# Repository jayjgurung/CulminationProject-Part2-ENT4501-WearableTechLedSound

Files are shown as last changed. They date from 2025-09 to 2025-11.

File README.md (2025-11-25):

# Audio-Visual Reactive System Tech

By Jay Jung Gurung — Emerging Media Technology | Culmination Project II (MTEC 4501)

## Overview

Audio-Visual Reactive System Tech is an interactive hardware–software system that transforms real-time audio input into dynamic LED visualizations. Built using an ESP32 microcontroller, an I2S MEMS microphone, WS2812B LEDs, and a custom PCB, this project explores embedded systems, acoustics, digital signal processing, and wearable audiovisual design.

The system analyzes incoming sound using an FFT (Fast Fourier Transform) and maps frequency energy to visual patterns, brightness, and color behavior. Additional control inputs (potentiometers, infrared remote, buttons, sensors) allow the user to modify the visual output and sensitivity on the fly.

This project aims to create an elegant, portable, and customizable audio-reactive LED module suitable for performance, stage design, wearables, and experimental media-technology applications.

---

## Features

- Real-time audio analysis via ESP32 I2S interface
- FFT-driven LED visualization (frequency bins → light patterns)
- Custom PCB designed in KiCad 8/9
- 3D-printed enclosure modeled in Autodesk Fusion 360
- WS2812B LED output with multiple animation modes
- Potentiometer-based sensitivity control
- Optional IR remote support for future expansion
- Modular design for wearable or tabletop use

---

## Hardware Components

- ESP32-WROVER-IE DevKit
- INMP441 (or similar) I2S MEMS microphone
- WS2812B LED strip or 5-LED chain
- Potentiometer for sensitivity
- IR receiver (optional)
- USB-C Li-ion charging board
- 21700 lithium battery
- Custom PCB (routed & manufactured)
- 3D-printed casing

---

## Software / Tools

- Arduino IDE (ESP32 Core v3.x)
- KiCad 8/9 (schematic & PCB design)
- Autodesk Fusion 360 (enclosure modeling)
- FastLED library
- arduinoFFT library
- ESP-IDF I2S driver (new API)

---

## Repository Structure

```text
CULMINATIONPROJECT-PART2-ENT4501-WEARABLETECHLEDSOUND/
│
├── Agile_Reports/
│   ├── 01_Agile_Sprint_Entry.md
│   ├── 02_Agile_Sprint_Entry.md
│   ├── 03_Agile_Sprint_Entry.md
│   ├── 04_Agile_Sprint_Entry.md
│   ├── 05.1_Agile_Sprint_Entry.md
│   └── 05.2_Agile_Sprint_Entry.md
│
├── Docs/
│   ├── Budget Report/
│   ├── KiCad/
│   ├── Panel Feedback/
│   ├── Reference/
│   └── Timeline/
│
├── Iteration_Plans/
│   └── IterationPlan-Roadmap.md
│
├── Presentations/
│   ├── Culmination-Part1-ProgressReport_Presentation_Fall2024.pdf
│   ├── Jury#1 Presentation links -JayGurung-fall2025.md
│   ├── Presentation_#2_JayGurung.pptx
│   └── Presentation-w-video-link.md
│
├── src/
│   ├── Arduino IDE/
│   └── KiCad/
│
├── .gitignore
└── README.md
```

---

## System Workflow

1. Microphone captures audio through I2S
2. ESP32 samples audio (e.g., 16 kHz)
3. FFT processes frames (e.g., 1024 samples)
4. Frequency bins are mapped to LED color, brightness, and animations
5. Potentiometer adjusts sensitivity threshold
6. LEDs render animations in real time

---

## Visual Modes (examples)

- Low-frequency pulsing
- Mid-range bar-graph effect
- High-frequency sparkle
- Full-spectrum rainbow reactive
- Silence → idle animation

---

## Current Status

- Hardware wiring and soldering complete
- PCB v1 assembled and tested
- Audio capture and FFT working
- LED visualization stable
- Pot control implemented
- 3D casing in prototype stage

---

## Acknowledgements

- Mentored by Professor Dr. David Smith
- Open-source libraries: FastLED, arduinoFFT
- Espressif documentation & community forums

---

## License

This project is for academic use under MTEC 4501 at City Tech. Feel free to reference or fork with credit.
Audio-Visual Reactive System Tech

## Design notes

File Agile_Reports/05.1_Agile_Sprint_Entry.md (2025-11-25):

Agile Sprint Log (Iteration Report)

Project Title: WearableTech-AV-JayG
Sprint #: 3
Date Range: Sept 18 – Sept 29 (Week 8 – 9 Development & Debugging Phase)
Prepared by: Jay J Gurung

⸻

1. Workflow Steps & Build Progress
	•	Power System
	•	Battery + USB-C charger integration continues to function as intended.
	•	Verified safe boot cycles under both USB and battery modes.
	•	Microcontroller & Processing
	•	ESP32-WROVER in use (selected for additional memory and I2S handling).
	•	FFT pipeline stable at 1024-point, 16 kHz sample rate.
	•	Implemented calibration via potentiometer input (GPIO34) to control sensitivity thresholds.
	•	LED Control
	•	WS2812B 5-LED chain mapped to FFT bands.
	•	Adjusted band thresholds to improve high-frequency LED triggering.
	•	Serial output added for monitoring per-band amplitude values.
	•	Microphone
	•	I2S MEMS microphone wiring complete (WS, SCK, SD pins verified).
	•	Confirmed digital input streaming with test code; calibration in progress.
	•	New Feature (IR Remote)
	•	Began integrating IR remote input for mode toggling (ambient vs. audio-reactive).

⸻

2. Component Upgrade Assessment
	•	Potentiometer
	•	Repurposed as a mic sensitivity dial.
	•	Verified analog input on GPIO34; prevents overdriving LED output.
	•	LEDs
	•	Improved mapping of treble band; now more responsive with realistic sound levels.
	•	IR Remote
	•	Testing basic IR decode library for ESP32.
	•	Initial command mapping planned (mode switching, brightness control).

⸻

3. Issues Encountered
	•	Permanent LED On
	•	Low-frequency LED occasionally stays lit due to baseline noise floor.
	•	Requires further threshold adjustment with pot + code calibration.
	•	Mic Sensitivity
	•	Potentiometer heating issue noted during testing; possible need for resistor or wiring adjustment.
	•	Code Stability
	•	Encountered I2S driver conflicts (resolved by switching to new API: i2s_std.h).
	•	Core dump errors observed when flashing larger builds; investigated memory allocation.

⸻

4. Updates to Code & Components
	•	Code
	•	Updated to new ESP32 I2S standard API (i2s_std.h).
	•	Added potentiometer input for live sensitivity scaling.
	•	Added serial debugging for band-by-band amplitude values.
	•	Started framework for IR remote handling.
	•	Components
	•	Installed and tested I2S MEMS microphone.
	•	Integrated potentiometer control into live loop.
	•	WS2812B LEDs tuned with adjusted thresholds.

⸻

5. Future Iterations
	•	Finalize IR remote integration (mode toggling, brightness presets).
	•	Smooth LED flicker using moving average or exponential filter.
	•	Optimize FFT bin grouping for better distribution across 5 LEDs.
	•	Document mic calibration process (pot vs. hard-coded thresholds).
	•	Begin preparing visuals/slides for Jury #1 presentation.

⸻

6. Research Findings
	•	ESP32-WROVER handles I2S mic + FFT without performance bottleneck.
	•	Potentiometer provides flexible live calibration but requires safe wiring to prevent overheating.
	•	High-frequency FFT bins naturally have lower amplitude; scaling adjustments improve LED balance.
	•	Switching from legacy i2s.h to i2s_std.h ensures compatibility with ESP32 core v3.x.

⸻

7. Next Steps
	•	Complete IR remote command mapping.
	•	Fine-tune mic baseline and LED band thresholds with real audio.
	•	Add smoothing algorithm to stabilize LED flicker.
	•	Update GitHub repo with new code + circuit diagrams.
	•	Prepare Jury #1 deck: slides covering overview, current build, timeline, and budget.

⸻

8. Summary

The project has progressed into an integrated wearable audio-reactive system. The ESP32-WROVER now runs FFT analysis with an I2S MEMS mic input, mapped to a 5-LED WS2812B chain. A potentiometer provides live sensitivity control, addressing threshold calibration challenges. IR remote functionality has been initiated for flexible mode switching. Remaining work focuses on fine-tuning mic sensitivity, smoothing LED response, and preparing for the Jury #1 presentation.

⸻

9. Disclosures
	•	Research and documentation assisted by ChatGPT-5.
	•	Report compiled in Agile format for Sprint #5.

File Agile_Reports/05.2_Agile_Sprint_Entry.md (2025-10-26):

Agile Report #5.2 — Culmination Project II
Student: Jay Jung Gurung
Date Range: October 12 – October 19, 2025

⸻

Reflection on Jury #1 Feedback

What did you decide to change, refine, or revise based on jury feedback?
I decided to create a body for the design to give it a tangible form and help the next jury better understand what my system can do visually and functionally. I also added more LEDs and a potentiometer for greater control and responsiveness.

What materials (presentation, written documentation, or prototype) need the most improvement?
I plan to extend the LED setup from 5 to 25 addressable LEDs, add three additional potentiometers for parameter control, and ideally 3D-print a custom housing to encase the system and enhance presentation quality.

⸻

Retrospective (After Jury #1)

What went well:
The presentation successfully demonstrated the system’s core features and concept.

What didn’t:
The lack of a defined body or enclosure made it harder for the jury to visualize the final product’s real-world application.

What I learned:
Form and presentation are equally important as function. Giving the prototype a physical identity helps communicate design intent and use case more effectively.

⸻

Current State

I currently have rough sketches, updated code, a working prototype, and supporting documentation. The foundation of the reactive LED system is stable and ready for integration into a physical form.

⸻

User Story (Next Sprint Focus)

As a tech student who is into music and videography, I want to give my system a form that can be mounted on top of a camera hot shoe, serving as a compact audio-reactive LED attachment.

⸻

Acceptance Criteria (Given–When–Then)

Given that the physical body is still under design,
When the structure is completed and assembled,
Then I will have a working prototype that can be demonstrated as a functional camera accessory.

⸻

Definition of Done (DoD)

When a physical body/enclosure is constructed for the system and integrated with the LED and control components, the prototype will be considered complete.

⸻

Goals (Steps Toward the DoD)
	1.	Design and model the 3D enclosure for the LED box or camera-mount version.
	2.	Expand the LED matrix from 5 to 25 addressable pixels.
	3.	Integrate additional potentiometers for multi-parameter control.

⸻

Blockers (as Help Requests)
	•	Access to a 3D printer or fabrication tools for creating the enclosure.
	•	Guidance on power management and circuit safety for the expanded LED setup.
	•	Support in testing multiple potentiometers with the current ESP32 configuration.

⸻

Next Steps
	•	Continue refining the code and hardware integration.
	•	Begin physical assembly and wiring of the 5×5 LED grid.
	•	Prepare visuals (sketches and short demo video) for Sprint 5.3 presentation.

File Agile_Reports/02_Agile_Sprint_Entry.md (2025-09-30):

Agile Sprint Log (Iteration Report)

Project Title: WearableTech-AV-JayG
Sprint #: 1.2
Date Range: Sept 2 – Sept 16 (Week 2 - 3 Research)
Prepared by: Jay J Gurung

⸻

Sprint Stage Checklist
	✓	Speculate / Plan 
	✓	Research
	•	Design
	•	Make / Produce
	•	Publish / Present
	•	Assess

⸻

0. Review of Previous Sprint (CORE)
	•	Previous Sprint Goal: Identify and evaluate microphone options beyond the unreliable electret module tested last semester.
	•	Achieved / Not Achieved: Achieved — researched multiple alternatives, clarified suitability.
	•	Problems or Bottlenecks Found: Confusion between analog MEMS (ICS-40730) and digital I²S options; difficulty ensuring compatibility with ESP32.
	•	Feedback Received (peer/faculty/AI): Encouraged to consider digital Electret microphones but research indicated INMP441 would be better alternative to avoid analog gain/noise issues.
	•	Carry-over Tasks: Select a specific mic breakout to purchase and integrate into ESP32 testing.

⸻

1. Speculate / Plan (CORE)
	•	Current Sprint Goal (based on last assessment): Decide on a microphone module and supporting components that meet project needs for amplitude + frequency analysis.
	•	Key Tasks (checklist):
	•	Research MEMS microphones (digital vs analog).
	•	Verify ESP32 compatibility with chosen mic.
	•	Assess battery and charger modules for powering ESP32 + LEDs.
	•   Planned Deliverables: Research summary; finalized microphone choice; BOM for power and protection parts.
	•	Research Needed: Amplitude vs frequency detection methods, FFT library needs, and wiring requirements for I²S.

⸻

2. Research (OPTIONAL)
    Questions Investigated:
        •   Which microphone can reliably provide both amplitude and frequency data?
        •   Is a digital I²S mic superior to analog electret/AGC modules for wearables?
        •   What supporting components are needed for ESP32 + LED jacket builds?
	Sources Consulted:
        •   INMP441 datasheets and Arduino/ESP32 I²S examples.
        •   DFRobot Fermion SEN0526 (ICS-43434 I²S MEMS mic) documentation.
        •   Comparison to analog electret modules (MAX9814, MAX4466).
        •   Battery datasheets (LI21700JSV-50) and charger module specs (DFR0668).
	Findings / Insights:
	    •   INMP441 / Fermion SEN0526 (ICS-43434) are digital I²S microphones, plug-and-play with ESP32, ideal for FFT analysis and amplitude detection.
	    •   Analog MEMS (ICS-40730, electret mics) require amplification/ADC and are less stable; not recommended for frequency analysis.
	    •   ESP32 DevKitC handles I²S data + FFT comfortably; S3 variant offers more I/O and DSP headroom.
	    •   Battery: Jauch 21700 (5000 mAh) with PCM + fuse provides adequate runtime (2+ hours with LEDs).
	    •   Charger: DFR0668 is compatible but limited to 500 mA; overnight charging acceptable for class project.

⸻

3. Assess (CORE)
	•	Successes This Sprint: Narrowed mic choice to Fermion SEN0526 (I²S MEMS digital), confirmed ESP32 compatibility, identified battery/charger solutions, and safety components (polyfuse, capacitor, data resistor).
	•	Current Bottlenecks: Charger speed (10–12 h full charge); may need higher-current charger in future iterations.
	•	Feedback Received (peer/faculty/AI): Confirmed viability of digital MEMS approach; recommended prebuilt charger modules instead of bare ICs.
	•	Adjustments for Next Sprint: Order microphone, ESP32, LED strips, and charger. Begin bench tests with I²S mic → FFT → LED mapping pipeline.

4. Shopping list:
    •  https://www.digikey.com/short/525hn9th

5. Disclosures:
    -   Reaserch Assisted by ChatGpt.
    -   Report Summary and Compilation Assisted by Chatgpt.
    -   Research Archive : https://chatgpt.com/share/68b726d3-7894-8006-bfcb-972431b2e975

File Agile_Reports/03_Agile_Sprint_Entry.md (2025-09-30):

Agile Sprint Log (Iteration Report)

Project Title: WearableTech-AV-JayG
Sprint #: 1.3
Date Range: Sept 2 – Sept 16 (Week 2 - 3 Research)
Prepared by: Jay J Gurung

⸻

1. Workflow Steps and Code Analysis
	•	Initialization
	•	Original sketch initializes pins for LED output.
	•	Sets up the microphone input (analog or I2S depending on component).
	•	Serial monitor used for debugging.
	•	Loop Execution
	•	Continuously reads microphone signal.
	•	Maps raw amplitude values into brightness values for LEDs.
	•	Updates LEDs based on the mapped amplitude.
	•	Functions
	•	setup(): Prepares the environment, serial communication, and I/O pins.
	•	loop(): Handles real-time microphone reading and LED updates.
	•	Issues: No modularization of frequency analysis, hard-coded thresholds, and inefficient LED update cycle.

⸻

2. Component Upgrade Assessment
	•	Microphone Upgrade
	•	Moving from simple analog microphones → I2S MEMS microphones (INMP441 or ICS-40730).
	•	Advantage: Digital signal, higher accuracy, lower noise, direct FFT compatibility.
	•	LEDs Upgrade
	•	Old: Basic LED strips or single RGB LEDs.
	•	New: Addressable LED strips (WS2812B or SK6812) → allows mapping frequencies to different LED zones.
	•	Processing Unit Upgrade
	•	ESP32 recommended over Arduino Uno for:
	•	Higher processing power.
	•	Native I2S support.
	•	Built-in WiFi for possible remote features.

⸻

3. Issues Identified in Previous Sketch
	•	Only amplitude detection (no frequency mapping).
	•	Raw analog input was noisy, causing inaccurate LED flicker.
	•	LED update loop was slow → visible lag.
	•	No support for scaling brightness or splitting audio into frequency bands.
	•	No modular functions (all logic was dumped inside loop() instead of being separated into smaller reusable blocks).

⸻

4. Updates to Code & Components
	•	Code Updates
	•	Integrate FFT (Fast Fourier Transform) to split audio into low, mid, high bands.
	•	Use smoothing algorithms (moving average) to reduce flicker.
	•	Optimize LED updates using libraries like FastLED or Adafruit NeoPixel.
	•	Create modular functions: readAudio(), analyzeFrequency(), updateLEDs().
	•	Component Updates
	•	Switch to I2S microphone module (INMP441).
	•	Use ESP32 DevKitC for higher processing and WiFi support.
	•	Add Li-ion battery + charger module (DFR0668, TP4056, etc.) for portability.
	•	Use 5V addressable LED strips with level shifter if needed.

⸻

5. Future Iterations
	•	Phase 1: Real-time audio amplitude → LED brightness.
	•	Phase 2: Frequency band analysis → map bass, mids, treble to different LED channels.
	•	Phase 3: Add WiFi control → remote app or OSC/MQTT protocol.
	•	Phase 4: Integrate with music apps (DJ software, Serato, Ableton) for synced visualizations.

⸻

6. Research Findings
	•	I2S MEMS microphones have better noise rejection and allow FFT processing directly.
	•	FFT libraries for ESP32 (ArduinoFFT, ESP-DSP) perform well in real-time for small sample sizes (e.g., 1024).
	•	Addressable LEDs (WS2812B) are industry standard for music-reactive installations.
	•	Power consumption: LED strips draw high current (up to 60mA per LED at full brightness white). A Li-ion + 5V boost converter is required.
	•	Remote options: ESP32 can publish FFT results over WiFi (MQTT/OSC) to external apps.

⸻

7. Next Steps
	•	Replace microphone with INMP441 and test I2S audio capture.
	•	Implement FFT analysis for 3 frequency bands.
	•	Map frequency bands to LED zones (bass = red, mids = green, highs = blue).
	•	Add smoothing to LED brightness changes.
	•	Power test with Li-ion + charger module.
	•	Begin planning WiFi integration for remote control.

8.  Summary

        The project is transitioning from a basic microphone-to-LED system into an advanced audio-reactive LED platform. The initial sketch was limited to amplitude detection and lacked modularity, frequency analysis, and efficient LED control. Planned upgrades include adopting an ESP32 for enhanced processing and WiFi capability, integrating I2S MEMS microphones for accurate audio input, and utilizing addressable LED strips for flexible visualization. Code improvements will focus on FFT-based frequency band analysis, smoothing algorithms, and optimized LED update routines. Future iterations are designed to map frequency ranges to LED zones, incorporate portable Li-ion power solutions, and enable WiFi-based remote control. The next steps involve testing the INMP441 microphone, implementing FFT, refining LED responsiveness, evaluating power consumption, and preparing for remote connectivity features.

9. Disclosures:
    -   Reaserch Assisted by ChatGpt 5: Agent Mode
    -   Report Summary and Compilation Assisted by Chatgpt.

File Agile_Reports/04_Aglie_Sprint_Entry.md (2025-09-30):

Agile Sprint Log (Iteration Report)

Project Title: WearableTech-AV-JayG
Sprint #: 2
Date Range: Sept 13 – Sept 17 (Week 4 – 7 Research & Build Progress)
Prepared by: Jay J Gurung

⸻

1. Workflow Steps & Build Progress
	•	Power System
	•	Integrated rechargeable lithium-ion battery module with USB-C charger board.
	•	Added physical power switch to control current flow between the battery and ESP32.
	•	System successfully runs untethered from USB power.
	•	Microcontroller & Processing
	•	ESP32 DevKitC in use (chosen for I2S mic support and FFT capability).
	•	Current code implements FFT with 5 frequency bands (bass → treble).
	•	LED Control
	•	WS2812B addressable LED chain installed with 5 LEDs.
	•	Each LED mapped to one frequency band.
	•	LEDs respond to FFT magnitudes with brightness scaling.
	•	Microphone
	•	Microphone hardware selection done (I2S MEMS mic planned).
	•	Physical installation step remains pending.

⸻

2. Component Upgrade Assessment
	•	Battery & Power
	•	Added lithium-ion battery with charger board (USB-C).
	•	Power switch for safe on/off control during battery mode.
	•	LEDs
	•	Transitioned from earlier 3-band mapping to 5-band LED chain.
	•	Microphone
	•	I2S microphone module is the next hardware addition for clean signal capture.

⸻

3. Issues Encountered
	•	One LED in chain remained permanently on until sensitivity values are tuned.
	•	Mic not yet installed, preventing real-world FFT validation.
	•	Sensitivity thresholds for each band need calibration.

⸻

4. Updates to Code & Components
	•	Code
	•	Expanded FFT from 3 to 5 bands.
	•	LED mapping scaled to 5 LEDs, one per band.
	•	Serial monitor support being prepared for debugging loudness per band.
	•	Components
	•	Added rechargeable battery + USB-C charger board.
	•	Integrated hardware power switch.
	•	WS2812B LED chain mounted and responsive.

⸻

5. Future Iterations
	•	Install I2S MEMS microphone (INMP441 or equivalent).
	•	Fine-tune sensitivity thresholds for LED response.
	•	Add smoothing filters to reduce flicker.
	•	Test full portable operation (battery run-time).
	•	Begin exploring optional WiFi/OSC expansion for remote monitoring.

⸻

6. Research Findings
	•	5-band frequency mapping provides more dynamic visualization than 3-band setup.
	•	ESP32 performance remains stable with 1024-point FFT at 16 kHz sample rate.
	•	Battery operation with switch provides safe, portable use case.
	•	Addressable LEDs (WS2812B) continue to be efficient for small band-to-LED mapping.

⸻

7. Next Steps
	•	Complete installation of microphone.
	•	Validate FFT input against real sound sources.
	•	Calibrate LED sensitivity values via Serial monitor testing.
	•	Document portable power consumption with multimeter readings.

⸻

8. Summary

The project has advanced from planning into a functional 5-band audio-reactive LED system powered by a rechargeable lithium-ion battery. A USB-C charger module and physical switch ensure safe, portable operation. The ESP32 executes FFT processing and drives 5 WS2812B LEDs mapped to 5 frequency bands. The next major milestone is the installation and calibration of the I2S microphone, which will enable true real-time audio reactivity. Once the mic is integrated, the focus will shift to tuning LED sensitivity, smoothing, and preparing for possible WiFi expansion.

⸻

9. Disclosures
	•	Research and documentation assisted by ChatGPT-5.
	•	Report compiled in Agile format for Sprint #4.

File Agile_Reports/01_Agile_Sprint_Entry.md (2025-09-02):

Project Title: WearableTech-AV-JayG
Sprint #: 1
Date Range: Sept 2 - Sept 16 (Week 2 & Week 3)
Prepared by: Jay J Gurung

Purpose: 
The purpose of this sprint is to asses and identify, plan refine my project ideas at where it stands and overcome some challenges facing the projects in small steps.

The goal of the first half of my Culmination Project was to assemble a rough prototype that could manage to do some basic physical computing processes like reading and reacting to the input it is given. Although it did do some basic things I ran into some issues with the type of microphone sensor i had, which did not behave as planned.
    Although I am happy with what I got done so far, I would need to do some extensive research so I can find the right microphone that can read and react to it as it should.
THe Microphone I aquired had sensitive potentiometer that was not consistant with the reading, on top of that it could only read the amplitude. While my project required a mic that could read amplitude and frequency of the live audio, my attempt to get just use the amplitude reading did not fully work as planned because of unreliable hardware component in the mic unit.
    The feedback i received can be found in documents posted in the following  directory: "Docs/PanelFeedback-Fall2024" 
Images, documentation and video demo of my project's latest progress can be found in "Assets" folder.

My plan for the next 2 weeks is to Research on microphone sensors, and aquire the right components and test it in the Arduion IDE. In addition, I will be modifying the code in "/Prototype_Code" folder to cater to the needs of the new mic component.
    My target before Week4 is to be able to communicate LED lights with with the mic using IDE.

Checklist:
    1. Research microphone for Arduino 
    2. Order parts
    3. Communicate and program the sensor and output.
    4. Refine

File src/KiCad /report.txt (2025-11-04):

Warning: Width correction constrained.  The width correction value must be in the range of [0.000001 mm; 0.199999 mm] for the current design rules.
Plotted to '/Users/jayjgurung/Library/CloudStorage/GoogleDrive-jay.gurung@mail.citytech.cuny.edu/My Drive/FALL 2025/CulminationProject-Part2-ENT4501-WearableTechLedSound/KiCad /GERBER/ReactiveLED-PCB-F_Cu.gtl'.
Plotted to '/Users/jayjgurung/Library/CloudStorage/GoogleDrive-jay.gurung@mail.citytech.cuny.edu/My Drive/FALL 2025/CulminationProject-Part2-ENT4501-WearableTechLedSound/KiCad /GERBER/ReactiveLED-PCB-B_Cu.gbl'.
Plotted to '/Users/jayjgurung/Library/CloudStorage/GoogleDrive-jay.gurung@mail.citytech.cuny.edu/My Drive/FALL 2025/CulminationProject-Part2-ENT4501-WearableTechLedSound/KiCad /GERBER/ReactiveLED-PCB-F_Paste.gtp'.
Plotted to '/Users/jayjgurung/Library/CloudStorage/GoogleDrive-jay.gurung@mail.citytech.cuny.edu/My Drive/FALL 2025/CulminationProject-Part2-ENT4501-WearableTechLedSound/KiCad /GERBER/ReactiveLED-PCB-B_Paste.gbp'.
Plotted to '/Users/jayjgurung/Library/CloudStorage/GoogleDrive-jay.gurung@mail.citytech.cuny.edu/My Drive/FALL 2025/CulminationProject-Part2-ENT4501-WearableTechLedSound/KiCad /GERBER/ReactiveLED-PCB-F_Silkscreen.gto'.
Plotted to '/Users/jayjgurung/Library/CloudStorage/GoogleDrive-jay.gurung@mail.citytech.cuny.edu/My Drive/FALL 2025/CulminationProject-Part2-ENT4501-WearableTechLedSound/KiCad /GERBER/ReactiveLED-PCB-B_Silkscreen.gbo'.
Plotted to '/Users/jayjgurung/Library/CloudStorage/GoogleDrive-jay.gurung@mail.citytech.cuny.edu/My Drive/FALL 2025/CulminationProject-Part2-ENT4501-WearableTechLedSound/KiCad /GERBER/ReactiveLED-PCB-F_Mask.gts'.
Plotted to '/Users/jayjgurung/Library/CloudStorage/GoogleDrive-jay.gurung@mail.citytech.cuny.edu/My Drive/FALL 2025/CulminationProject-Part2-ENT4501-WearableTechLedSound/KiCad /GERBER/ReactiveLED-PCB-B_Mask.gbs'.
Plotted to '/Users/jayjgurung/Library/CloudStorage/GoogleDrive-jay.gurung@mail.citytech.cuny.edu/My Drive/FALL 2025/CulminationProject-Part2-ENT4501-WearableTechLedSound/KiCad /GERBER/ReactiveLED-PCB-User_Drawings.gbr'.
Plotted to '/Users/jayjgurung/Library/CloudStorage/GoogleDrive-jay.gurung@mail.citytech.cuny.edu/My Drive/FALL 2025/CulminationProject-Part2-ENT4501-WearableTechLedSound/KiCad /GERBER/ReactiveLED-PCB-Edge_Cuts.gm1'.
Created Gerber job file '/Users/jayjgurung/Library/CloudStorage/GoogleDrive-jay.gurung@mail.citytech.cuny.edu/My Drive/FALL 2025/CulminationProject-Part2-ENT4501-WearableTechLedSound/KiCad /GERBER/ReactiveLED-PCB-job.gbrjob'.
Info: Done.
Info: Done.

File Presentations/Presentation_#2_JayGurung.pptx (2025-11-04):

## REACTIVE LED SYSTEM

CULMINATION PROJECT
CITY TECH
2025 / FALL / NOVEMBER 4

Jay J Gurung

## Contents Jay J Gurung REACTIVE LED SYSTEM

1.

2.

PRODUCT DESIGN INSPO & SKETCH

SYSTEM UPGRADE & EXPANSION

PCB DESIGN - KiCad

ENCLOSURE DESIGN - Autodesk Fusion

NEXT STEPS

3.

4.

5.

## Jay J Gurung REACTIVE LED SYSTEM CAMVATE 96led Camera Video Fill Light SmallRig RM 25C Mini LED Video Light RGB PANEL PRO 2.0 1. PRODUCT DESIGN INSPIRATIONS

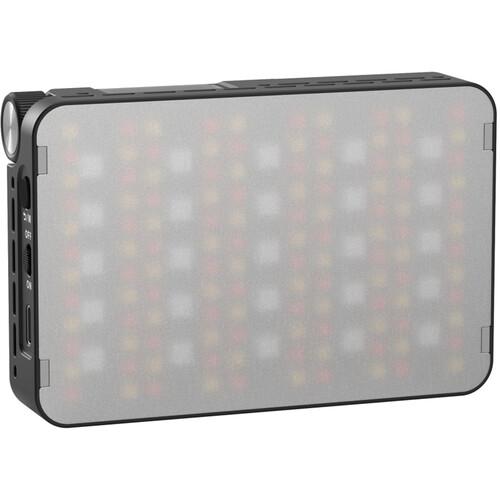
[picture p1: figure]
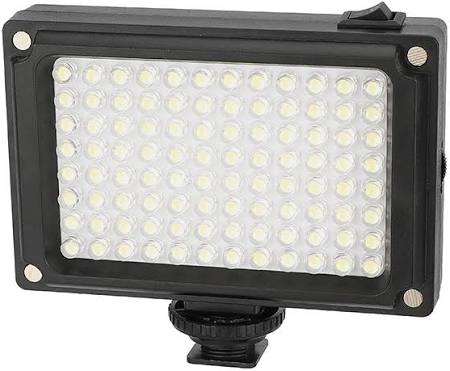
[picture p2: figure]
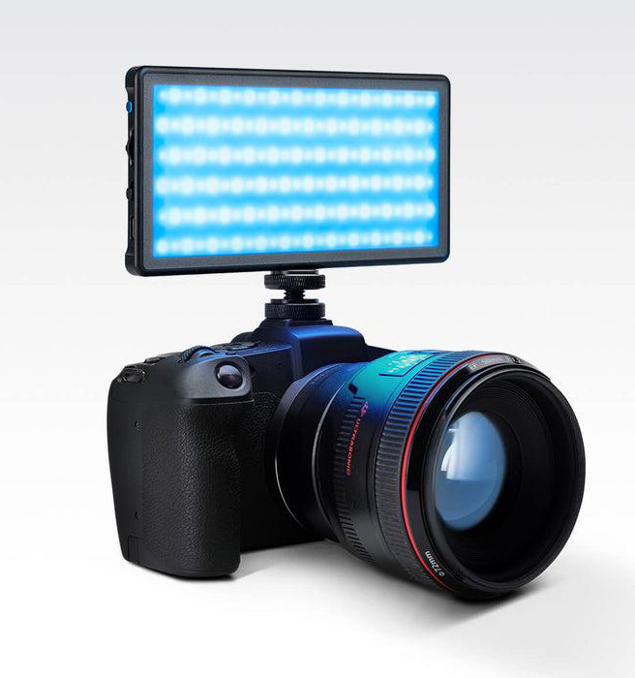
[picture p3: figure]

Controllable via App
RGB Colors
Rechargeable
Price $149
link (https://lumecube.com/products/panel-pro?nbt=nb%3Aadwords%3Ax%3A21932544690%3A%3A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)

SIMPLE LED with magnetic filter attachment, white or yellow temperature.
Runs on 2 AA batteries
Price $20
Link (https://www.camvate.com/products/camvate-96led-camera-video-fill-light-for-vlogging-studio-photography-3452)

Rechargable.
Adjustable Color Temp knob
Price $60
Link (https://www.bhphotovideo.com/c/product/1903738-REG/smallrig_5357_rm_25c_mini_led.html/?ap=y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)

## REACTIVE LED SYSTEM 1. PRODUCT DESIGN SKETCH Jay J Gurung

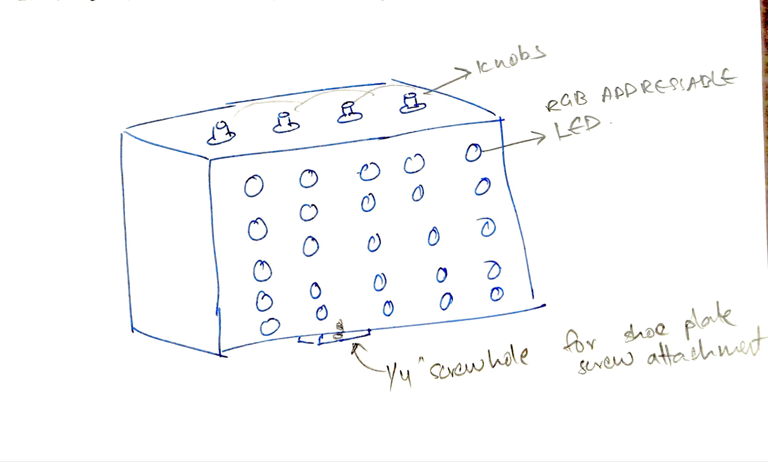
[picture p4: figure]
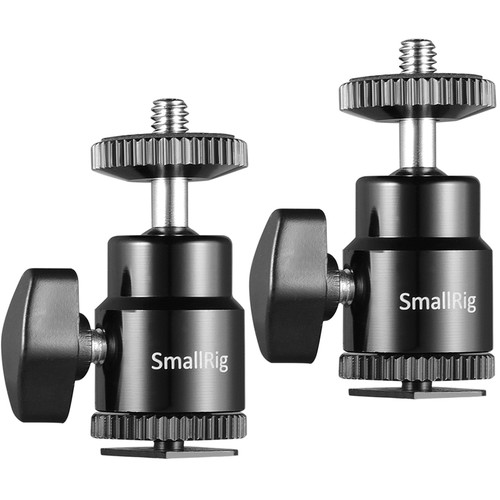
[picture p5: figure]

Expanded from 5 LED to 25 5 LEDs are mapped to each bandwidth instead of 1 LED for each bandwidth. Adds more brightness. System scalability. Will be adding more features. Updated the sketch to account for addressable LED to work with 25 LEDS.
Updated the sketch to account for 3 new pots. Functions not assigned yet. Changes Made What It Does Expanded from 1 control knob to 4 pots. Arduino IDE Sketch 3.0 Jay J Gurung Company Name 2. SYSTEM EXPANSION 1 2 3

## REACTIVE LED SYSTEM 3. PCB DESIGN - SCHEMATICS Jay J Gurung

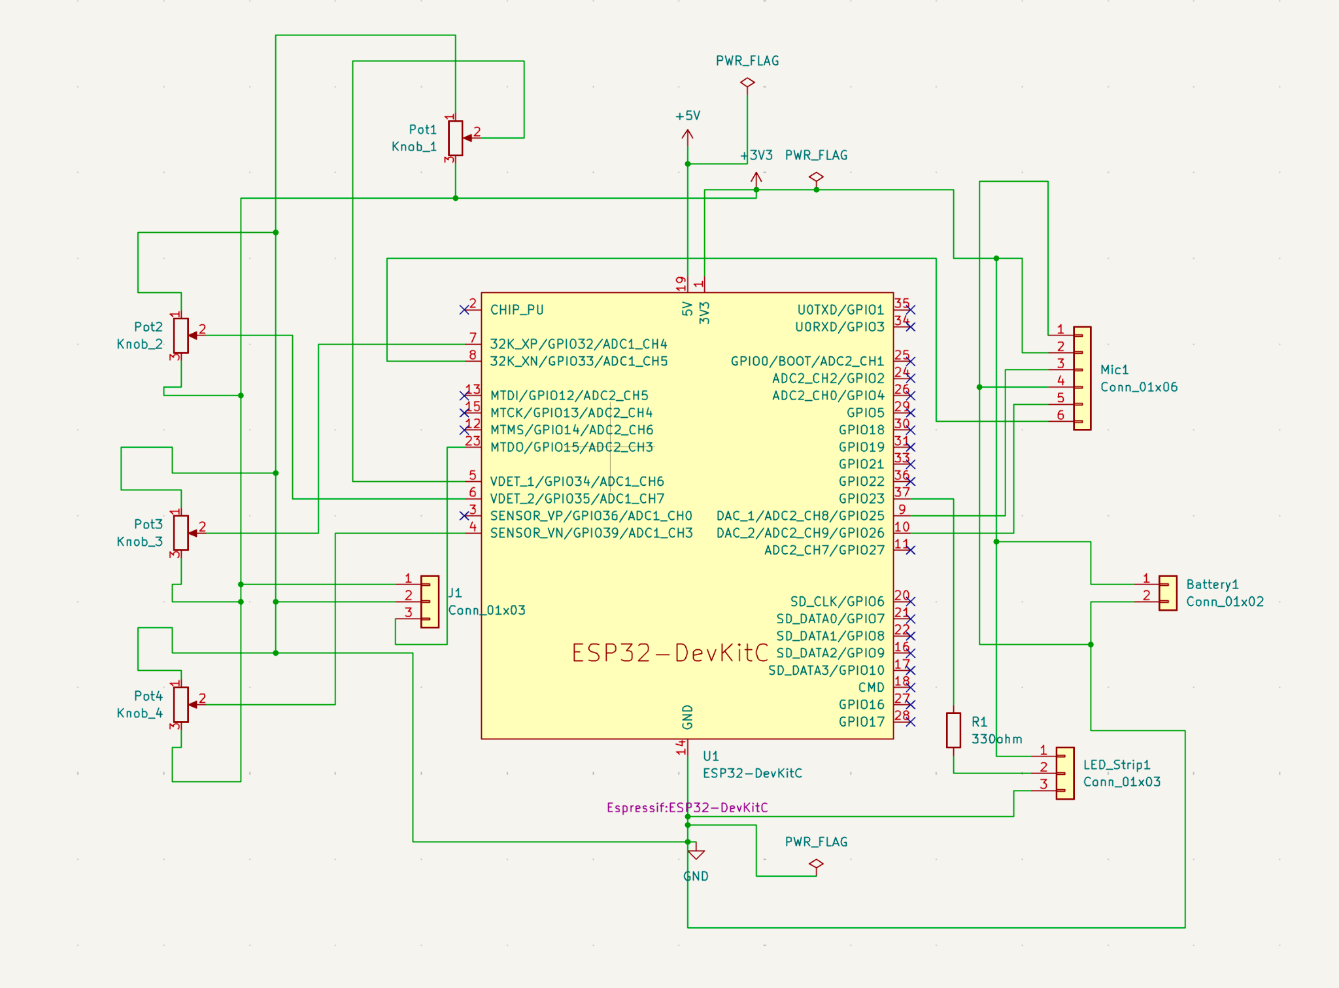
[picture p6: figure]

- Chose and imported symbols for all key parts
- Set correct electrical pin types (power, input, passive, etc.) and assigned footprints for each component.
- Connected components using wires for clear visual routing of power, data, and control signals.
- Ran Electrical Rules Check, fixed all errors.

## REACTIVE LED SYSTEM 3. PCB DESIGN - PCB EDITOR Jay J Gurung

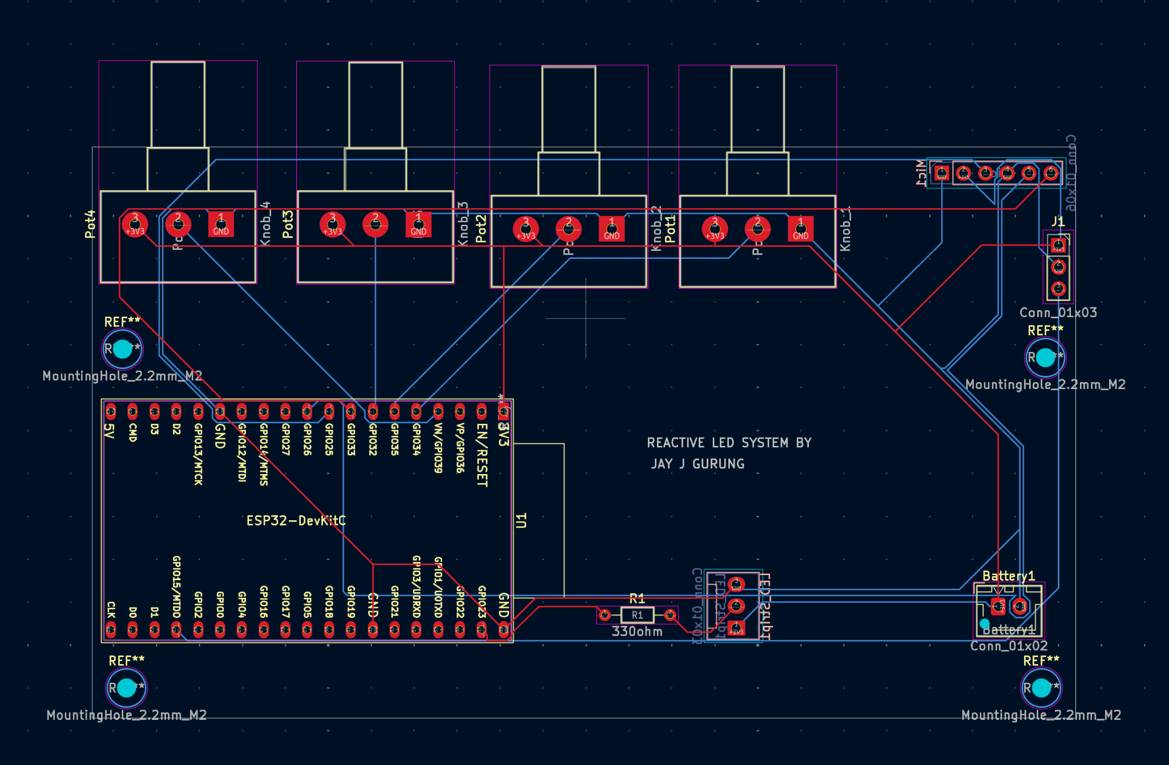
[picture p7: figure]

- Updated PCB from Schematic and Strategically arranged ESP32, microphone, potentiometers, LEDs, and connectors for compact layout and easy wiring access.
- Drew custom board shape and added screw holes for future enclosure mounting.
- Routed all power, signal, and ground traces
- Verified clearances, hole sizes, and track widths; fixed all unconnected nets and overlap warnings.
- Exported Gerber, Drill, and Step files for PCB fabrication and 3D modeling in Fusion 360.

## REACTIVE LED SYSTEM 3. PCB DESIGN - PCB EDITOR Jay J Gurung

## 4. ENCLOSURE DESIGN - Autodesk Fusion Jay J Gurung REACTIVE LED SYSTEM

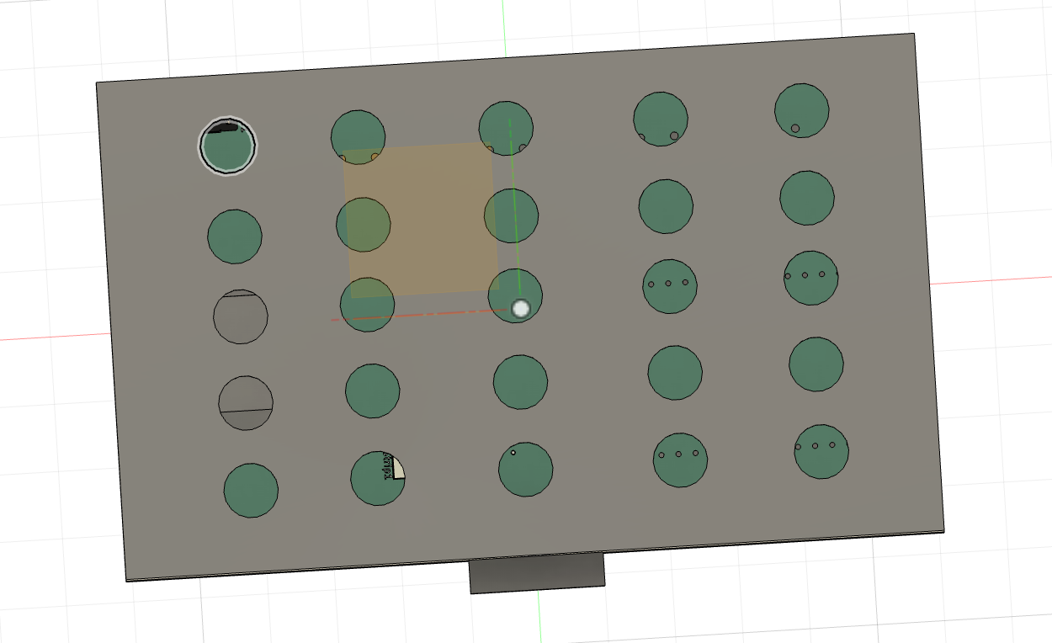
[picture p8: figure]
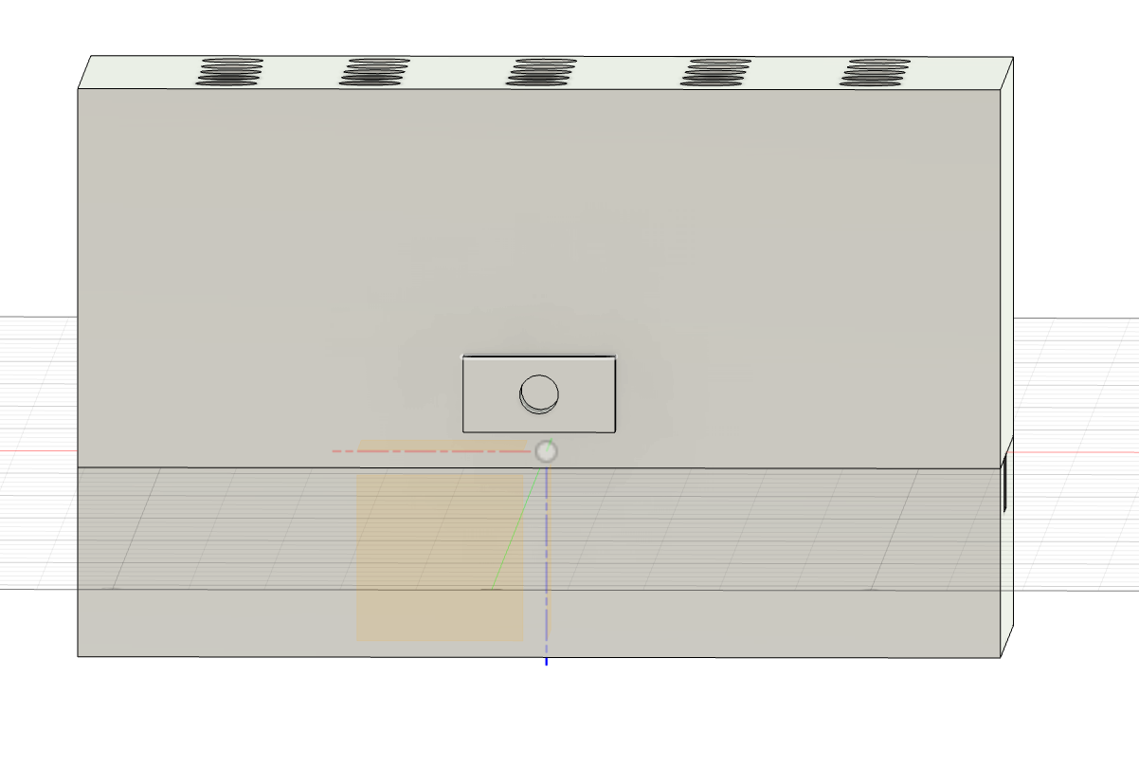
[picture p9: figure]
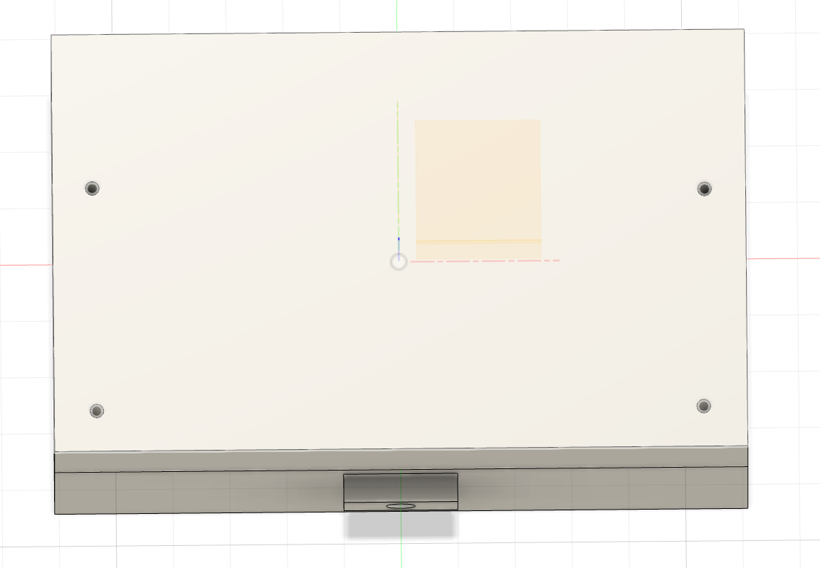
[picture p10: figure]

Front

Bottom

Back

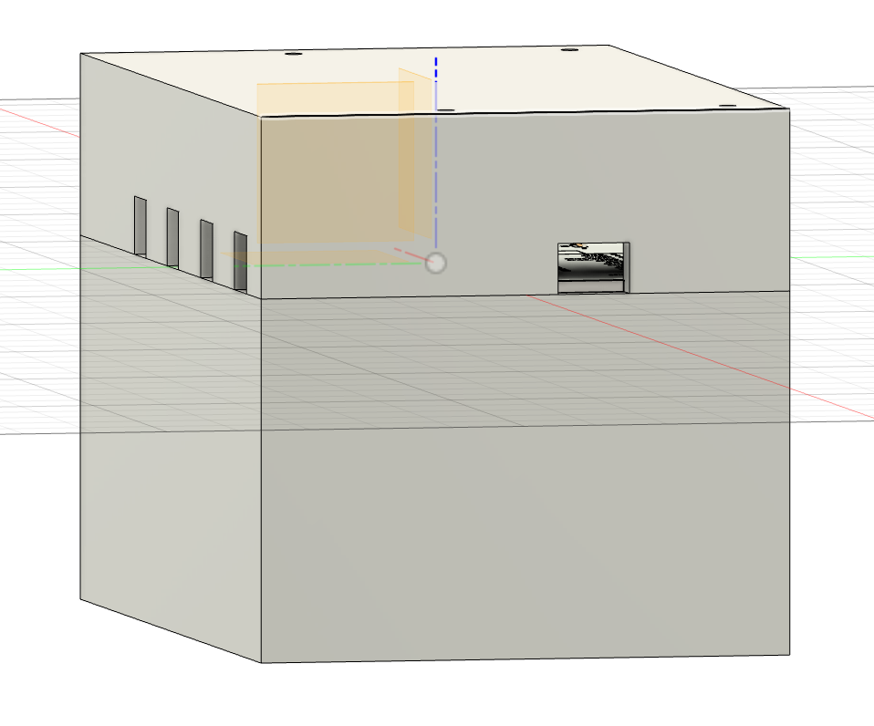
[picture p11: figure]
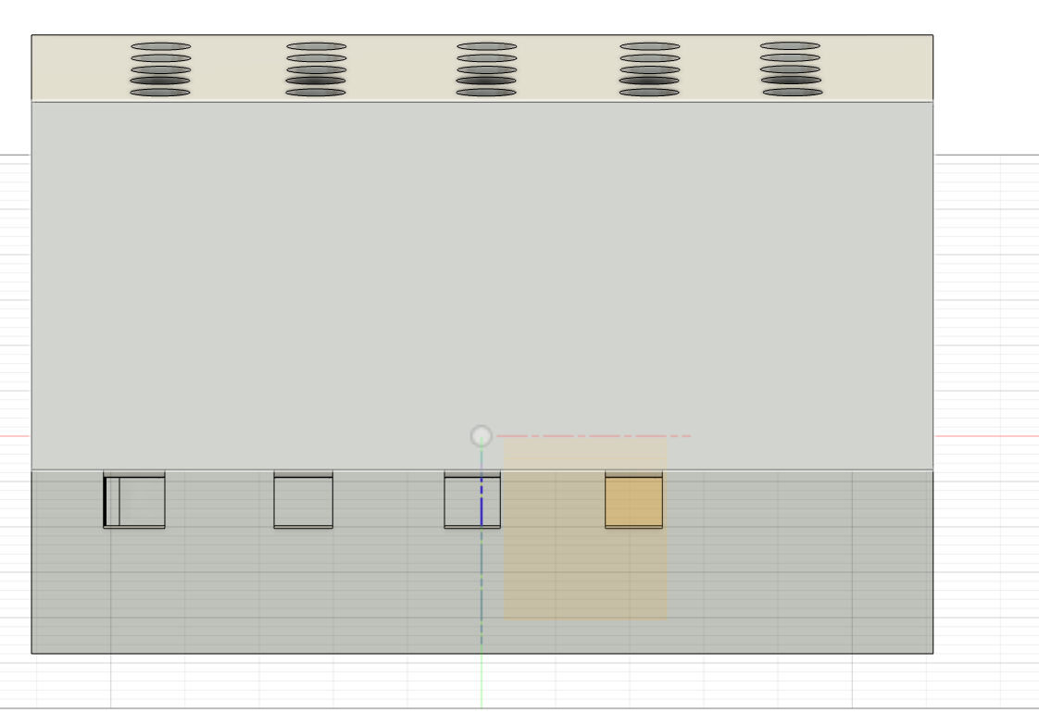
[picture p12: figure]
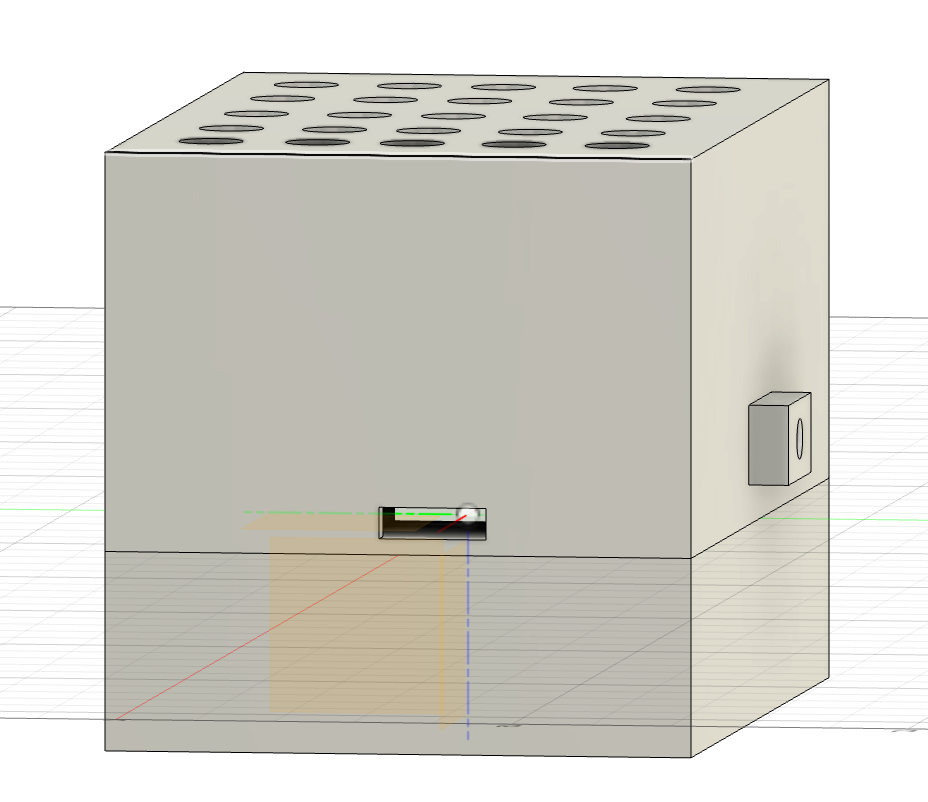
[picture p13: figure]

Left

Top

Right

## 4. ENCLOSURE DESIGN - Autodesk Fusion Jay J Gurung REACTIVE LED SYSTEM

Demo of 3D VIEW
In Software

Order PCBs Submit Designs to order custom PCB board 3d Print the Enclosure for the board. Add more functions to the system so that all the knobs are functional. Steps What It Does 3d Print Add More Functions Jay J Gurung Company Name 5. NEXT STEPS 1 2 3 Assemble all the parts and playtest. Assembly 4

## REACTIVE LED SYSTEM THE END Jay J Gurung

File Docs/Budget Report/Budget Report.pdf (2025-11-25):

Budget Report

Category | Item | Quantity | Unit Cost (USD) | Total Cost (USD)
Microcontroller & Core Electronics | ESP32-WROVER-IE DevKitC | 1 | 15 | 15
Microcontroller & Core Electronics | INMP441 / Fermion I2S Microphone | 1 | 10 | 10
Microcontroller & Core Electronics | WS2812B LED Strip (25 LEDs) | 1 | 12 | 12
Microcontroller & Core Electronics | Potentiometer 10k Ohm | 3 | 1.5 | 4.5
Microcontroller & Core Electronics | IR Receiver Module | 1 | 2 | 2
Microcontroller & Core Electronics | Rotary Knobs | 3 | 0.75 | 2.25
Microcontroller & Core Electronics | Push Buttons (momentary) | 2 | 0.5 | 1
Microcontroller & Core Electronics | Jumper Wire Set | 1 | 5 | 5
Power System | USB-C Li-ion Charger Module | 1 | 9 | 9
Power System | 21700 Li-ion Battery | 1 | 12 | 12
Power System | Power Switch | 1 | 1 | 1
Power System | Voltage Regulator Module | 1 | 3 | 3
PCB Fabrication | PCB Manufacturing (PCBWay/JLCPCB) | 1 | 30 | 30
PCB Fabrication | PCB Shipping | 1 | 12 | 12
Enclosure & 3D Printing | PLA Filament (120g) | 1 | 3 | 3
Enclosure & 3D Printing | Test Print Material | 1 | 2 | 2
Enclosure & 3D Printing | Screws / Hardware Pack | 1 | 5 | 5
Tools (Non-Consumable) | Soldering Iron | 1 | 0 | 0
Tools (Non-Consumable) | Wire Strippers | 1 | 0 | 0
Tools (Non-Consumable) | Multimeter | 1 | 0 | 0
Tools (Non-Consumable) | 3D Printer Access | 1 | 0 | 0
TOTAL | | | | 131.75

1

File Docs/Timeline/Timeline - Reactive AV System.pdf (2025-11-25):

Jay Gurung

Audio Visual Reactive Tech System

ENT 4501

November 24, 2025

📆 12-Week Project Timeline (WearableTech-AV)

Weeks 1–9: Completed Work

Weeks 10–12: Remaining Work

🟦 Week 1 — Ideation & Early Research (Completed)

- Defined core concept: audio-reactive LED wearable device
- Initial research on ESP32, MEMS mics, FFT analysis, LED libraries
- Gathered examples, benchmarks, and design approaches

🟦 Week 2 — Proof of Concept Setup (Completed)

- Tested ESP32 with FastLED and basic LED animations
- Connected microphone to confirm raw audio input
- Built very early audio → light reaction sketch
- Confirmed core technical feasibility

🟦 Week 3 — Hardware Experiments & Sensor Tests (Completed)

- Tested multiple MEMS mics (INMP441, Fermion)
- Verified I2S pins and stable audio sampling
- Experimented with potentiometer sensitivity mapping
- Early breadboard prototype

🟦 Week 4 — First Prototype Structure (Completed)

- Audio-reactive code with FFT bands working
- Stable 5-LED demo version
- Added basic UI elements in p5.js
- Started systematic Agile documentation

🟦 Week 5 — Adding System Upgrades (Completed)

- Added additional potentiometers for more control
- Integrated IR receiver
- Introduced multi-mode LED behavior
- Improved code organization and sensitivity tuning

🟦 Week 6 — Schematic Design in KiCad (Completed)

- Created complete schematic
- Selected footprints, verified pin mappings
- Added power module, mic, potentiometers, LEDs
- Troubleshot symbol/footprint mismatches

🟦 Week 7 — PCB Layout (Completed)

- Full PCB routing + organization
- Added mounting holes, labels, and silkscreen
- Verified trace width, spacing, and 3D preview
- First 3D file export (.STEP) for enclosure work

🟦 Week 8 — Casing Development in Fusion 360 (Completed)

- Imported PCB 3D model into Fusion
- Designed early enclosure structure
- Identified screw-hole size, clearances, and alignment issues
- Tested placement for LED strip & pot cutouts

🟦 Week 9 — Repository Audit & Documentation Cleanup (Completed)

- Organized GitHub repo into clear folders
- Added Agile logs, updated README structure
- Documented POC → LVP progression
- Began preparing presentation outline

🟧 Weeks 10–12: Future Timeline (Remaining Work)

🟧 Week 10 — Final Hardware & Enclosure Completion

Goal: Lock in all physical components

- Finalize PCB (silkscreen, mounting adjustments, cleanup)
- Export/verify Gerbers, drill files
- Finalize Fusion 360 enclosure (mounting pillars, vents, LED slots)
- Test full hardware with updated code
- Re-check all wiring logic and assembly spacing
- Add updated media (photos/screenshots) to repo

🟧 Week 11 — Full System Testing & Documentation Build

Goal: Make the system presentation-ready

- Print enclosure test or finalize existing enclosure
- Assemble complete system (ESP32 + mic + pots + LEDs + case)
- Run stability tests (brightness, noise floor, mic gain)
- Polish Arduino & p5.js code
- Finalize README + documentation navigation
- Add diagrams (wiring, PCB screenshots, enclosure images)
- Write Owner’s Manual / Process Notes draft

🟧 Week 12 — Final Presentation & Polishing

Goal: Deliver final showcase version

- Record final demo video (multiple modes + performance demo)
- Complete slideshow (problem, process, challenges, result)
- Finalize Lessons Learned section
- Mark all repo items as FINAL (tag release version)
- Prepare device for live demo
- Submit & present final project

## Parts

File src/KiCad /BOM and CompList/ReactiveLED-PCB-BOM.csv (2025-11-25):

Reference | Value | Footprint
U1 | ESP32-DevKitC | Espressif:ESP32-DevKitC
Battery1 | Conn_01x02 | Connector_JST:JST_XH_B2B-XH-AM_1x02_P2.50mm_Vertical
J1 | Conn_01x03 | Connector_PinSocket_2.54mm:PinSocket_1x03_P2.54mm_Vertical
LED_Strip1 | Conn_01x03 | Connector:FanPinHeader_1x03_P2.54mm_Vertical
Mic1 | Conn_01x06 | Connector_PinHeader_2.54mm:PinHeader_1x06_P2.54mm_Vertical
Pot1 | Knob_1 | Potentiometer_THT:Potentiometer_Alps_RK163_Single_Horizontal
Pot2 | Knob_2 | Potentiometer_THT:Potentiometer_Alps_RK163_Single_Horizontal
Pot3 | Knob_3 | Potentiometer_THT:Potentiometer_Alps_RK163_Single_Horizontal
Pot4 | Knob_4 | Potentiometer_THT:Potentiometer_Alps_RK163_Single_Horizontal
R1 | 330ohm | Resistor_THT:R_Axial_DIN0204_L3.6mm_D1.6mm_P7.62mm_Horizontal

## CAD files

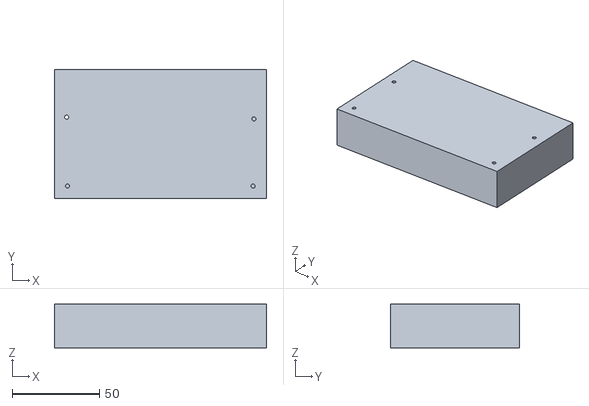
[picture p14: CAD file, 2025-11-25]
src/KiCad /STL Files for 3d Printing/Bottom Body.stl
121.7 x 74.0 x 25.0

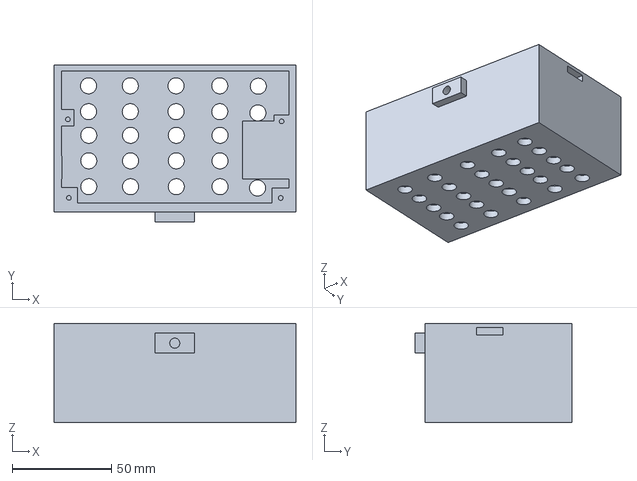
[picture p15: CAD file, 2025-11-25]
src/KiCad /STL Files for 3d Printing/UMS3_Top Body.3mf
121.7 x 79.0 x 50.0 mm

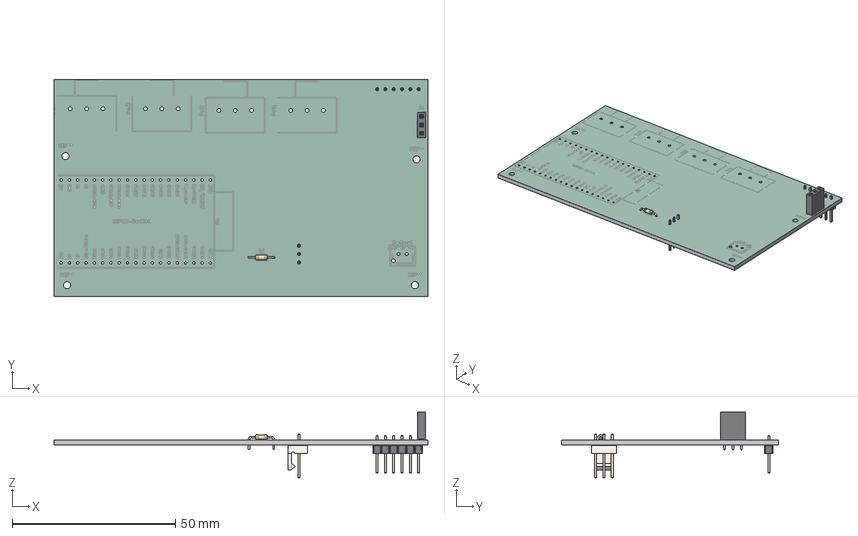
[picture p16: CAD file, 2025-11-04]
src/KiCad /STL Files for 3d Printing/ReactiveLED-PCB_3d design.step
114.5 x 66.5 x 20.2 mm
PinSocket_1x03_P2.54mm_Vertical
R_Axial_DIN0204_L3.6mm_D1.6mm_P7.62mm_Horizontal
PinHeader_1x06_P2.54mm_Vertical
FanPinHeader_1x03_P2.54mm_Vertical
ReactiveLED-PCB_silkscreen x 2
ReactiveLED-PCB_soldermask x 2
ReactiveLED-PCB_PCB

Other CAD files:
src/KiCad /STL Files for 3d Printing/UMS3_Bottom Body.3mf
src/KiCad /STL Files for 3d Printing/Top Body.stl

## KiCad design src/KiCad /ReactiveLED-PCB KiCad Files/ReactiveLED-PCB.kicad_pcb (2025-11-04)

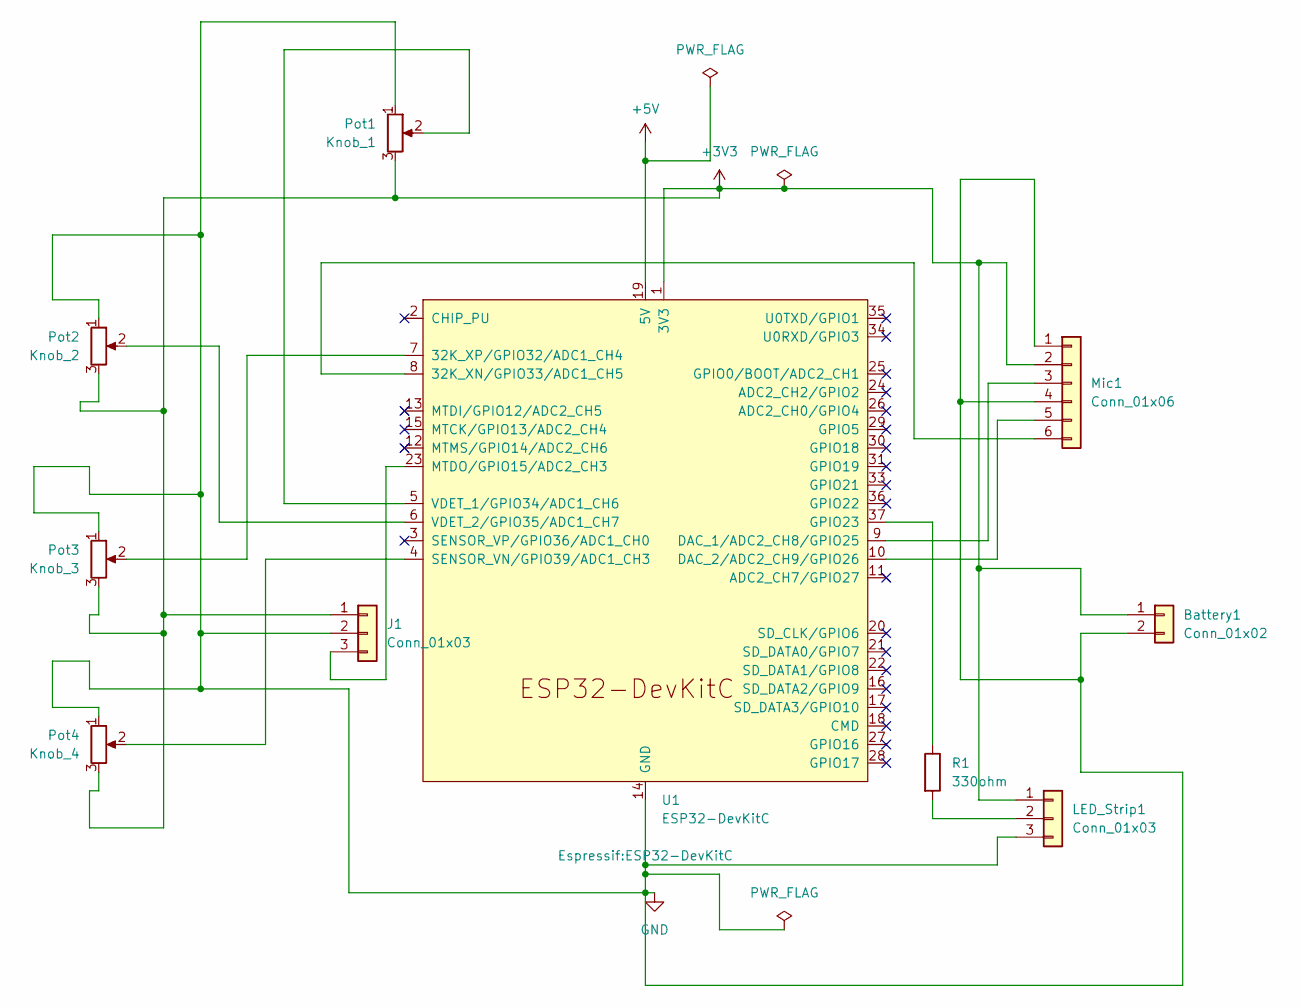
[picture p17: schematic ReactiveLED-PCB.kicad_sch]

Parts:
Battery1: Conn_01x02; JST_XH_B2B-XH-AM_1x02_P2.50mm_Vertical
J1: Conn_01x03; PinSocket_1x03_P2.54mm_Vertical
LED_Strip1: Conn_01x03; FanPinHeader_1x03_P2.54mm_Vertical
Mic1: Conn_01x06; PinHeader_1x06_P2.54mm_Vertical
Pot1: Knob_1; Potentiometer_Alps_RK163_Single_Horizontal
Pot2: Knob_2; Potentiometer_Alps_RK163_Single_Horizontal
Pot3: Knob_3; Potentiometer_Alps_RK163_Single_Horizontal
Pot4: Knob_4; Potentiometer_Alps_RK163_Single_Horizontal
R1: 330ohm; R_Axial_DIN0204_L3.6mm_D1.6mm_P7.62mm_Horizontal
U1: ESP32-DevKitC

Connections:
+3V3: Battery1.1, J1.1 (vcc), LED_Strip1.1, Mic1.2, Pot1.3, Pot2.3, Pot3.3, Pot4.3, U1.1 (3V3)
+5V: U1.19 (5V)
GND: Battery1.2, J1.2 (gnd), LED_Strip1.3, Mic1.1, Mic1.4, Pot1.1, Pot2.1, Pot3.1, Pot4.1, U1.14 (GND), U1.32 (GND), U1.38 (GND)
unnamed: J1.3 (out), U1.23 (MTDO/GPIO15/ADC2_CH3)
unnamed: LED_Strip1.2, R1.2
unnamed: Mic1.6, U1.8 (32K_XN/GPIO33/ADC1_CH5)
unnamed: Mic1.5, U1.10 (DAC_2/ADC2_CH9/GPIO26)
unnamed: Mic1.3, U1.9 (DAC_1/ADC2_CH8/GPIO25)
unnamed: Pot3.2, U1.7 (32K_XP/GPIO32/ADC1_CH4)
unnamed: R1.1, U1.37 (GPIO23)
unnamed: Pot4.2, U1.4 (SENSOR_VN/GPIO39/ADC1_CH3)
unnamed: Pot1.2, U1.5 (VDET_1/GPIO34/ADC1_CH6)
unnamed: Pot2.2, U1.6 (VDET_2/GPIO35/ADC1_CH7)

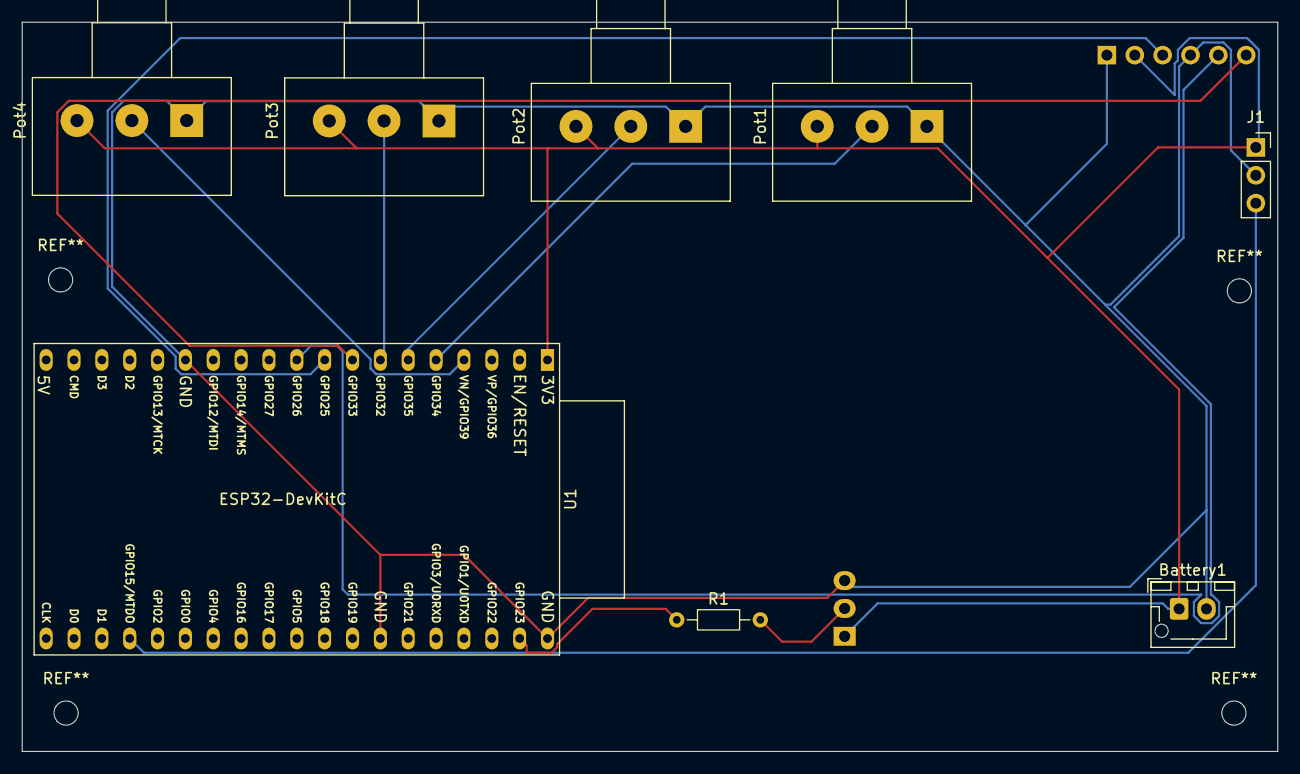
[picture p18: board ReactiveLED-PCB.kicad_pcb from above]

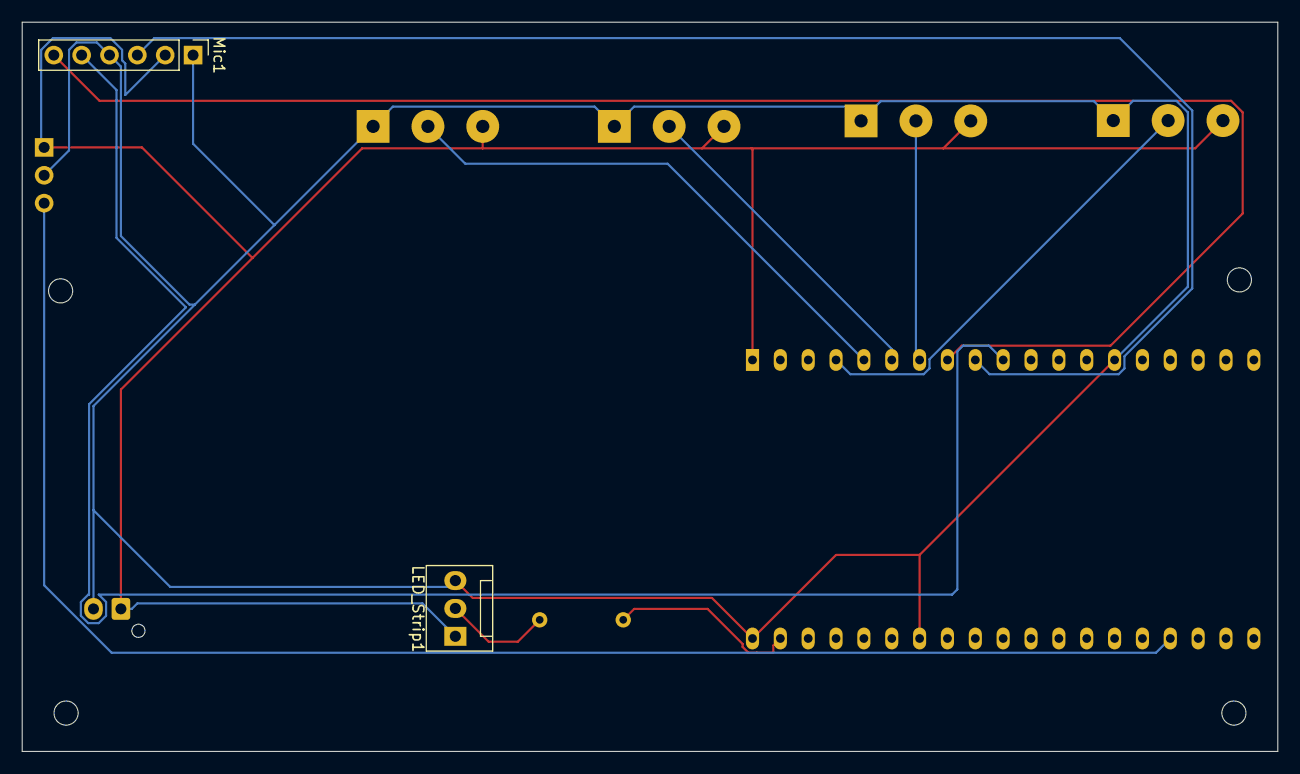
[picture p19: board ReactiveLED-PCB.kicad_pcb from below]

Board: 2 copper layers, 114.5 x 66.5 mm, 10 parts (2 on the bottom side), 12 nets.

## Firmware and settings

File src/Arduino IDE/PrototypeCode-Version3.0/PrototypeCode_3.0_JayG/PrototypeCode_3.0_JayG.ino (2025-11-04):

#include <Arduino.h>
#include <driver/i2s_std.h>   // NEW I2S API (ESP32 core v3.x)
#include <FastLED.h>
#include <arduinoFFT.h>

/*** ------------------ PIN DEFINITIONS ------------------ ***/
#define I2S_WS_PIN   25   // LRCLK / WS
#define I2S_SCK_PIN  26   // BCLK / SCK
#define I2S_SD_PIN   33   // DOUT from mic -> ESP32

#define LED_DATA_PIN 23

// ---- LED layout: 5 bands × 5 LEDs each ----
#define NUM_BANDS    5
#define GROUP_SIZE   5
#define NUM_LEDS     (NUM_BANDS * GROUP_SIZE)

#define LED_TYPE     WS2812B
#define LED_ORDER    GRB
#define MAX_BRIGHT   200

CRGB leds[NUM_LEDS];

/*** POTENTIOMETERS ***/
#define POT1_PIN 34   // active: sensitivity control
#define POT2_PIN 35   // reserved for future use
#define POT3_PIN 32   // reserved for future use
#define POT4_PIN 39   // reserved for future use

/*** ------------------ AUDIO / FFT SETTINGS ------------------ ***/
const uint32_t SAMPLE_RATE = 16000;
const int      FFT_SIZE    = 1024;
const uint16_t FRAME_MS    = 20;   // ~50 FPS

/*** SOUND WEIGHTING & GATING PARAMETERS ***/
static const float TOP_BIN_HZ = 6000.0f;              // ignore ultra-high hiss
static const float WEIGHT_SLOPE_DB_PER_OCT = -3.0f;   // pink-ish correction

// Base post-floor gates
static const float BAND_GATE_BASE[NUM_BANDS] = {0.53f, 0.18f, 0.20f, 0.22f, 0.14f};
// Extra divisors per-band to tame highs
static float BAND_EXTRA_DIV[NUM_BANDS] = {3.60f, 1.10f, 1.10f, 1.15f, 1.80f};
static const float HYST_DELTA_B[NUM_BANDS] = {0.11f, 0.03f, 0.03f, 0.03f, 0.03f};

// Envelope time constants
static float ATTACK_MS  = 20.0f;
static float RELEASE_MS = 90.0f;
static float ATTACK_A, RELEASE_A;
static inline float alpha_for_ms(float tau_ms, float dt_ms) {
  return 1.0f - expf(-dt_ms / fmaxf(tau_ms, 1.0f));
}

// Band state variables
static float bandEnv[NUM_BANDS]   = {0};
static float bandFloor[NUM_BANDS] = {0.05f, 0.06f, 0.03f, 0.03f, 0.03f};
static bool  bandOn[NUM_BANDS]    = {false,false,false,false,false};

// Band edges (sub → treble)
static const float edgesHz[NUM_BANDS + 1] = {240, 360, 520, 1200, 2500, 8000};

/*** ------------------ I2S MICROPHONE SETUP ------------------ ***/
static i2s_chan_handle_t i2s_rx = nullptr;

static void setupI2S() {
  i2s_chan_config_t chan_cfg = I2S_CHANNEL_DEFAULT_CONFIG(I2S_NUM_0, I2S_ROLE_MASTER);
  i2s_new_channel(&chan_cfg, nullptr, &i2s_rx);   // RX only

  i2s_std_config_t std_cfg = {
    .clk_cfg  = I2S_STD_CLK_DEFAULT_CONFIG(SAMPLE_RATE),
    .slot_cfg = I2S_STD_PHILIPS_SLOT_DEFAULT_CONFIG(I2S_DATA_BIT_WIDTH_32BIT,
                                                    I2S_SLOT_MODE_MONO),
    .gpio_cfg = {
      .mclk = I2S_GPIO_UNUSED,
      .bclk = (gpio_num_t)I2S_SCK_PIN,
      .ws   = (gpio_num_t)I2S_WS_PIN,
      .dout = I2S_GPIO_UNUSED,
      .din  = (gpio_num_t)I2S_SD_PIN
    }
  };
  std_cfg.slot_cfg.slot_mask = I2S_STD_SLOT_LEFT;

  i2s_channel_init_std_mode(i2s_rx, &std_cfg);
  i2s_channel_enable(i2s_rx);
}

/*** ------------------ FFT SETUP ------------------ ***/
static double vReal[FFT_SIZE];
static double vImag[FFT_SIZE];
ArduinoFFT<double> FFT(vReal, vImag, FFT_SIZE, SAMPLE_RATE);

/*** ------------------ UTILITY FUNCTIONS ------------------ ***/
static inline float clamp01(float x){ return x < 0 ? 0 : (x > 1 ? 1 : x); }
static inline float fastMagf(float re, float im) {
  float a = fabsf(re), b = fabsf(im);
  return (a > b) ? (a + 0.4f*b) : (b + 0.4f*a);
}
static inline float pinkWeight(float hz) {
  if (hz < 30.0f) hz = 30.0f;
  float oct = logf(hz/30.0f)/logf(2.0f);
  float db  = WEIGHT_SLOPE_DB_PER_OCT * oct;
  return powf(10.0f, db/20.0f);
}

/*** ------------------ BAND INITIALIZATION ------------------ ***/
static bool bandsInited = false;
static int kTop = 0, kEdge[NUM_BANDS + 1];
static void bandsInit() {
  if (bandsInited) return;
  float binHz = (float)SAMPLE_RATE / (float)FFT_SIZE;
  kTop = (int)floorf(TOP_BIN_HZ / binHz);
  if (kTop > (FFT_SIZE/2 - 1)) kTop = FFT_SIZE/2 - 1;
  for (int i = 0; i < NUM_BANDS + 1; ++i) {
    int k = (int)floorf(edgesHz[i] / binHz);
    if (k < 1) k = 1;
    if (k > kTop) k = kTop;
    kEdge[i] = k;
  }
  bandsInited = true;
}

/*** ------------------ I2S BLOCK READ ------------------ ***/
static void readI2SBlockToFFT(float micGain) {
  int32_t raw[FFT_SIZE];
  size_t need = sizeof(raw), got = 0;

  while (got < need) {
    size_t br = 0;
    i2s_channel_read(i2s_rx, ((uint8_t*)raw) + got, need - got, &br, portMAX_DELAY);
    got += br;
  }

  // Convert and remove DC offset
  float mean = 0.f;
  static int16_t s16[FFT_SIZE];
  for (int i=0; i<FFT_SIZE; i++) {
    s16[i] = (int16_t)(raw[i] >> 11);
    mean += s16[i];
  }
  mean /= FFT_SIZE;

  for (int i=0; i<FFT_SIZE; i++) {
    float centered = ((float)s16[i] - mean) * micGain;
    vReal[i] = (double)centered;
    vImag[i] = 0.0;
  }
}

/*** ------------------ ADC SETUP ------------------ ***/
static inline void adcSetup() {
  analogReadResolution(12); // 0..4095
  analogSetPinAttenuation(POT1_PIN, ADC_11db);
  pinMode(POT1_PIN, INPUT);
  pinMode(POT2_PIN, INPUT);
  pinMode(POT3_PIN, INPUT);
  pinMode(POT4_PIN, INPUT);
  (void)POT2_PIN; (void)POT3_PIN; (void)POT4_PIN;  // silence unused warnings
}

/*** ------------------ POT1 READ ------------------ ***/
static inline void readKnob(float &sensMul, float &visCut, float &micGain) {
  uint32_t acc = 0;
  for (int i=0; i<4; i++) acc += analogRead(POT1_PIN);
  float x = (acc / 4.0f) / 4095.0f;  // normalize 0..1

  // Mapping: smooth control for sensitivity, visual cutoff, and mic gain
  sensMul = 0.8f  + 1.8f * x;
  visCut  = 0.12f + 0.16f * x;
  micGain = 0.25f * powf(8.0f, x);
}

/*** ------------------ BAND PROCESSING ------------------ ***/
static void computeBandsCalmed_fromFFT(double *re, double *im, float outBands[NUM_BANDS], const float sensMul) {
  bandsInit();
  float sum[NUM_BANDS] = {0};
  float binHz = (float)SAMPLE_RATE / (float)FFT_SIZE;

  for (int k=1; k<=kTop; ++k) {
    float hz = k * binHz;
    float mag = fastMagf((float)re[k], (float)im[k]);
    float v = mag * pinkWeight(hz);
    int b=0; while (b<NUM_BANDS && k >= kEdge[b+1]) b++;
    if (b>NUM_BANDS-1) b=NUM_BANDS-1;
    sum[b] += v;
  }

  for (int b=0; b<NUM_BANDS; ++b) {
    int widthBins = max(1, kEdge[b+1] - kEdge[b]);
    float raw  = sum[b] / widthBins;

    static const float NORM_SCALE[NUM_BANDS] = {0.00012f, 0.00026f, 0.00028f, 0.00030f, 0.00050f};
    float norm = raw * NORM_SCALE[b] / BAND_EXTRA_DIV[b];
    norm = clamp01(norm);

    // Floor dynamics
    static const float FLOOR_ALPHA_UP[NUM_BANDS] = {0.00012f, 0.0012f, 0.0016f, 0.0016f, 0.0016f};
    static const float FLOOR_CEIL [NUM_BANDS]    = {0.18f,    0.50f,   0.50f,   0.50f,   0.50f};
    static const float FLOOR_LEAK[NUM_BANDS]     = {0.00055f, 0.00010f,0.00010f,0.00010f,0.00010f};

    bandFloor[b] = (1.0f - FLOOR_ALPHA_UP[b]) * bandFloor[b] + FLOOR_ALPHA_UP[b] * norm;
    bandFloor[b] = fminf(bandFloor[b], FLOOR_CEIL[b]);
    bandFloor[b] = fmaxf(0.0f, bandFloor[b] - FLOOR_LEAK[b]);

    float over = norm - bandFloor[b];
    if (over < 0) over = 0;

    const float gate = BAND_GATE_BASE[b] * sensMul;
    if (over < gate) over = 0;

    float a = (over > bandEnv[b]) ? ATTACK_A : RELEASE_A;
    bandEnv[b] = bandEnv[b] + a*(over - bandEnv[b]);

    outBands[b] = bandEnv[b];

    float h = HYST_DELTA_B[b];
    if (!bandOn[b]) bandOn[b] = (bandEnv[b] > gate + h);
    else            bandOn[b] = (bandEnv[b] > gate - h);
  }
}

/*** ------------------ COLOR + RENDER ------------------ ***/
static CRGB bandColor(int idx) {
  switch (idx) {
    case 0: return CRGB(0,255,0);
    case 1: return CRGB(128,255,0);
    case 2: return CRGB(255,255,0);
    case 3: return CRGB(255,128,0);
    default:return CRGB(255,0,0);
  }
}

static void renderBands(const float bands[NUM_BANDS], float visualCutoff) {
  for (int b=0; b<NUM_BANDS; ++b) {
    float v = clamp01(bands[b]);
    uint8_t bri = 0;
    if (bandOn[b] && v > visualCutoff) {
      float over = v - visualCutoff;
      float scaled = clamp01(over / (1.0f - visualCutoff));
      bri = (uint8_t)(scaled * 255);
    }
    CRGB c = bandColor(b);
    for (int i=0; i<GROUP_SIZE; ++i) {
      int idx = b*GROUP_SIZE + i;
      leds[idx] = c;
      leds[idx].nscale8_video(bri);
    }
  }
  FastLED.show();
}

/*** ------------------ ARDUINO SETUP / LOOP ------------------ ***/
void setup() {
  Serial.begin(115200);
  FastLED.addLeds<LED_TYPE, LED_DATA_PIN, LED_ORDER>(leds, NUM_LEDS);
  FastLED.setBrightness(MAX_BRIGHT);
  FastLED.setMaxPowerInVoltsAndMilliamps(4, 800);   // protect battery
  fill_solid(leds, NUM_LEDS, CRGB::Black);
  FastLED.show();

  ATTACK_A  = alpha_for_ms(ATTACK_MS, FRAME_MS);
  RELEASE_A = alpha_for_ms(RELEASE_MS, FRAME_MS);

  setupI2S();
  adcSetup();

  // optional LED self-test
  for (int i=0; i<NUM_LEDS; ++i) leds[i] = CRGB::White;
  FastLED.show();
  delay(200);
  fill_solid(leds, NUM_LEDS, CRGB::Black);
  FastLED.show();

  Serial.println("FFT 5-band visualizer | 25 LEDs | Pot1 active | Pots2–4 reserved.");
}

void loop() {
  static uint32_t lastMs = 0;
  uint32_t now = millis();
  if (now - lastMs < FRAME_MS) return;
  lastMs = now;

  // 1) Read control knob
  float sensMul, visualCutoff, micGain;
  readKnob(sensMul, visualCutoff, micGain);

  // 2) Capture audio + FFT
  readI2SBlockToFFT(micGain);
  FFT.windowing(vReal, FFT_SIZE, FFT_WIN_TYP_HANN, FFT_FORWARD);
  FFT.compute(vReal, vImag, FFT_SIZE, FFT_FORWARD);

  // 3) Compute bands
  float bands[NUM_BANDS];
  computeBandsCalmed_fromFFT(vReal, vImag, bands, sensMul);

  // 4) Render LEDs
  renderBands(bands, visualCutoff);

  // 5) Debug print
  for (int i=0; i<NUM_BANDS; i++) {
    uint8_t bri = (bands[i] > visualCutoff) ? (uint8_t)(bands[i] * 255) : 0;
    Serial.print("Band "); Serial.print(i); Serial.print(" :: ");
    Serial.print(bands[i], 4); Serial.print(',');
    Serial.print(BAND_GATE_BASE[i] * sensMul, 4); Serial.print(',');
    Serial.print(visualCutoff, 4); Serial.print(',');
    Serial.print(bandFloor[i], 4); Serial.print(',');
    Serial.print(bri);
    Serial.print(" | MicGain="); Serial.print(micGain, 2);
    Serial.println();
  }
  Serial.println("----");
}

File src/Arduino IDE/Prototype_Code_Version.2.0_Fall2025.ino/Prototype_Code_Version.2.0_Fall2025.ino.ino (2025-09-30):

#include <IRremote.h>
#include <FastLED.h>

// ===================== LED STRIP CONFIG =====================
#define NUM_LEDS 50          // Number of addressable LEDs
#define DATA_PIN 8           // Addressable LED data pin
#define LED_TYPE WS2812      // LED chipset
#define COLOR_ORDER GRB
CRGB leds[NUM_LEDS];

// ===== MCU-AWARE PIN MAP (ESP32-WROVER-IE safe header pins) =====
#if defined(ARDUINO_ARCH_ESP32)
  // Board in your photo lacks a GPIO5 header; use GPIO23 for WS2812 data.
  #define PIN_DATA 23   // WS2812 DIN
  #define PIN_IR   14   // IR receiver OUT (left side header labeled 14)
  #define PIN_LED1 16   // indicator LEDs
  #define PIN_LED2 17
  #define PIN_LED3 18
  #define PIN_LED4 19
  #define PIN_LED5 21
  #define PIN_MIC  34   // analog-only input (ADC1)
#else
  // AVR fallback (e.g., UNO)
  #define PIN_DATA 8
  #define PIN_IR   7
  #define PIN_LED1 2
  #define PIN_LED2 3
  #define PIN_LED3 4
  #define PIN_LED4 5
  #define PIN_LED5 6
  #define PIN_MIC  A0
#endif

// Bind the above to the names used by the rest of the sketch
#undef DATA_PIN
#define DATA_PIN PIN_DATA

const uint8_t IR_PIN   = PIN_IR;
const uint8_t LED1_PIN = PIN_LED1;
const uint8_t LED2_PIN = PIN_LED2;
const uint8_t LED3_PIN = PIN_LED3;
const uint8_t LED4_PIN = PIN_LED4;
const uint8_t LED5_PIN = PIN_LED5;
const uint8_t MIC_PIN  = PIN_MIC;

// ===================== AUDIO / MIC CONFIG =====================
// const uint8_t MIC_PIN = A0;          // Analog mic input
const uint16_t ADC_MAX = 1023;       // 10-bit ADC

// Adaptive baseline & envelope follower
// (two-pole EMA: slow for baseline (dc), faster for envelope)
float micBaseline = 512.0f;          // Start near mid-rail for electret/INMP modules
float micEMA = 512.0f;               // Fast envelope follower
const float BASELINE_ALPHA = 0.001f; // Super slow drift to track room noise
const float ENV_ALPHA      = 0.10f;  // Fast response to transients

// Thresholds derived from envelope (scaled 0..1 later)
uint16_t micThresholdRaw = 40;       // Minimum deviation to trigger (raw ADC units)

// Brightness dynamics
uint8_t globalBrightness = 128;      // Default brightness

// ===================== IR REMOTE CONFIG =====================
// const uint8_t IR_PIN = 7;            // IR receiver pin

// Known raw codes from the user's remote (NEC 32-bit, LSB first as provided previously)
// Power OFF
#define IR_POWER_OFF 0xE916FF00
// 1..6
#define IR_BTN_1 0xF30CFF00
#define IR_BTN_2 0xE718FF00
#define IR_BTN_3 0xA15EFF00
#define IR_BTN_4 0xF708FF00
#define IR_BTN_5 0xE31CFF00
#define IR_BTN_6 0xA55AFF00

// ===================== TIMING =====================
// Millis-based frame pacing to keep animations smooth and IR responsive
const uint16_t FPS = 90;                   // Target frames per second for LED updates
const uint32_t FRAME_DT = 1000UL / FPS;    // ms per frame
uint32_t lastFrameMs = 0;

// FX1 (noise fields) time scaling
#define TIME_FACTOR_HUE 60
#define TIME_FACTOR_SAT 100
#define TIME_FACTOR_VAL 100

// FX2 chase params
const uint8_t FX2_SPAN = 10;         // number of lit pixels in the train
uint16_t fx2Index = 0;               // moving head index

// FX3 gating delay
uint32_t fx3LastUpdate = 0;

// ===================== APP STATE =====================

enum Mode : uint8_t {
  MODE_IDLE = 0,
  MODE_FX1,
  MODE_FX2,
  MODE_FX3,
  MODE_MIC
};

volatile Mode mode = MODE_IDLE;        // Current mode
uint32_t lastIrCode = 0;               // Last non-zero IR code (to suppress repeats)

// ===================== FORWARD DECLARATIONS =====================
void handleIR();
void setMode(Mode m);
void clearStrip();
void showIndicators();
void readMicAndUpdateEnvelope();
void runFX1_Noise();
void runFX2_Chase();
void runFX3_RandomGated();
void runMIC_ThresholdBlink();

// ===================== SETUP =====================
void setup() {
  Serial.begin(115200);

  // --- Addressable LEDs ---
  FastLED.addLeds<LED_TYPE, DATA_PIN, COLOR_ORDER>(leds, NUM_LEDS);
  FastLED.setBrightness(globalBrightness);
  clearStrip();
  FastLED.show();

  // --- Indicators ---
  pinMode(LED1_PIN, OUTPUT);
  pinMode(LED2_PIN, OUTPUT);
  pinMode(LED3_PIN, OUTPUT);
  pinMode(LED4_PIN, OUTPUT);
  pinMode(LED5_PIN, OUTPUT);
  showIndicators();

  // --- IR ---
  IrReceiver.begin(IR_PIN, ENABLE_LED_FEEDBACK);

  // --- Mic ---
#if defined(ARDUINO_ARCH_ESP32)
  analogReadResolution(10);                 // 0..1023
  analogSetPinAttenuation(MIC_PIN, ADC_11db); // ~0..3.3V range
#endif
  analogRead(MIC_PIN); // warm-up dummy read

  delay(50);
}

// ===================== LOOP =====================
void loop() {
  handleIR(); // Always keep IR responsive

  // Pace the animation to a fixed FPS
  const uint32_t now = millis();
  if (now - lastFrameMs < FRAME_DT) return;
  lastFrameMs = now;

  // Update mic envelope every frame (low cost)
  readMicAndUpdateEnvelope();

  switch (mode) {
    case MODE_FX1: runFX1_Noise(); break;
    case MODE_FX2: runFX2_Chase(); break;
    case MODE_FX3: runFX3_RandomGated(); break;
    case MODE_MIC: runMIC_ThresholdBlink(); break;
    case MODE_IDLE:
    default:
      // Low-power idle: subtle breathing on first LED to show system is alive
      {
        uint8_t b = beatsin8(8, 8, 32); // slow subtle pulse 8-32
        leds[0] = CHSV(160, 200, b);
        for (int i = 1; i < NUM_LEDS; ++i) leds[i] = CRGB::Black;
        FastLED.show();
      }
      break;
  }
}

// ===================== IR HANDLER =====================
void handleIR() {
  if (!IrReceiver.decode()) return;
  const uint32_t code = IrReceiver.decodedIRData.decodedRawData;
  IrReceiver.resume();

  if (code == 0) return; // ignore spurious zeros
  if (code == lastIrCode) return; // simple de-bounce for repeats
  lastIrCode = code;

  Serial.print("IR: 0x"); Serial.println(code, HEX);

  if (code == IR_POWER_OFF) {
    setMode(MODE_IDLE);
    clearStrip();
    FastLED.show();
    return;
  }

  if (code == IR_BTN_1)      setMode(MODE_FX1);
  else if (code == IR_BTN_2) setMode(MODE_FX2);
  else if (code == IR_BTN_3) setMode(MODE_FX3);
  else if (code == IR_BTN_4) setMode(MODE_IDLE);
  else if (code == IR_BTN_5) { // brightness toggle 50% / 100%
    globalBrightness = (globalBrightness < 200) ? 255 : 128;
    FastLED.setBrightness(globalBrightness);
  }
  else if (code == IR_BTN_6) setMode(MODE_MIC);
}

void setMode(Mode m) {
  mode = m;
  showIndicators();
  // When switching modes, clear or reset per-FX state
  if (mode == MODE_FX2) fx2Index = 0;
  if (mode == MODE_FX3) fx3LastUpdate = millis();
}

void showIndicators() {
  digitalWrite(LED1_PIN, mode == MODE_FX1);
  digitalWrite(LED2_PIN, mode == MODE_FX2);
  digitalWrite(LED3_PIN, mode == MODE_FX3);
  digitalWrite(LED4_PIN, mode == MODE_IDLE);
  digitalWrite(LED5_PIN, mode == MODE_MIC);
}
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

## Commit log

2025-11-04 Added KiCad Files, New Sketch v.3
    Update
    [ReactiveLED-PCB-B_Cu.gbl, ReactiveLED-PCB-B_Mask.gbs, ReactiveLED-PCB-B_Paste.gbp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]
2025-11-25 Updated
    quick update
    [Bottom Body.stl, Budget Report.csv, ReactiveLED-PCB-BOM.csv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]
2025-11-25 update with dsstore
    added src folder
    [Bottom Body.stl, ReactiveLED-PCB-BOM.csv, ReactiveLED-PCB-CompList.csv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]
